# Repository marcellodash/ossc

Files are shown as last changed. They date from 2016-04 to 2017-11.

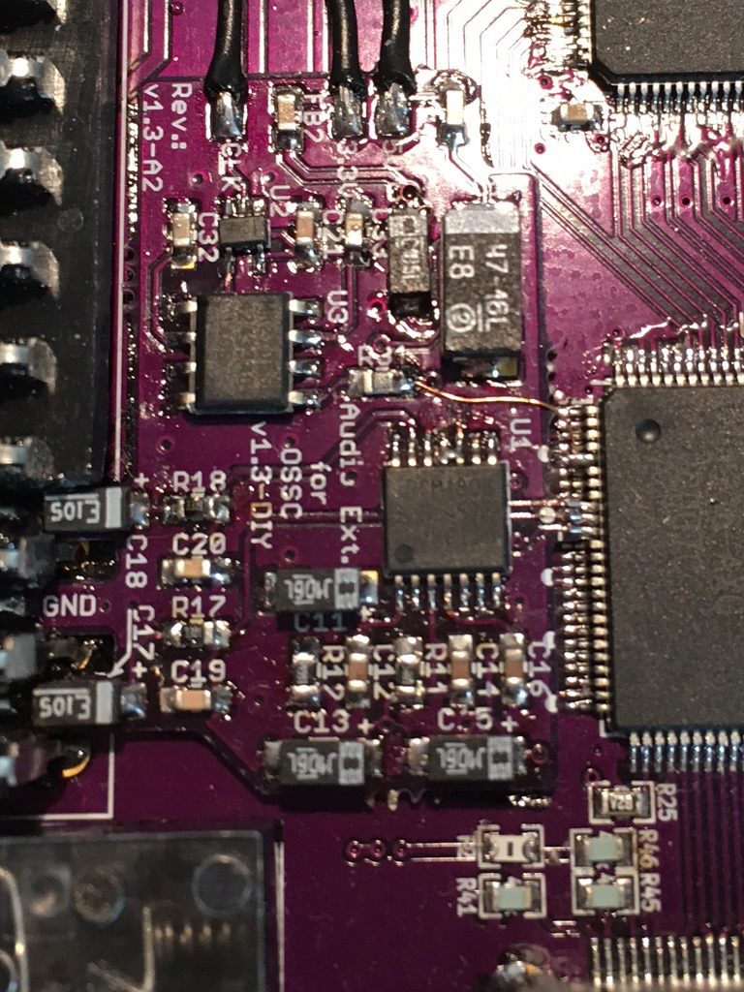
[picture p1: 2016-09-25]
diy-audio/installation/installation_mclk_10-v1.3.JPG

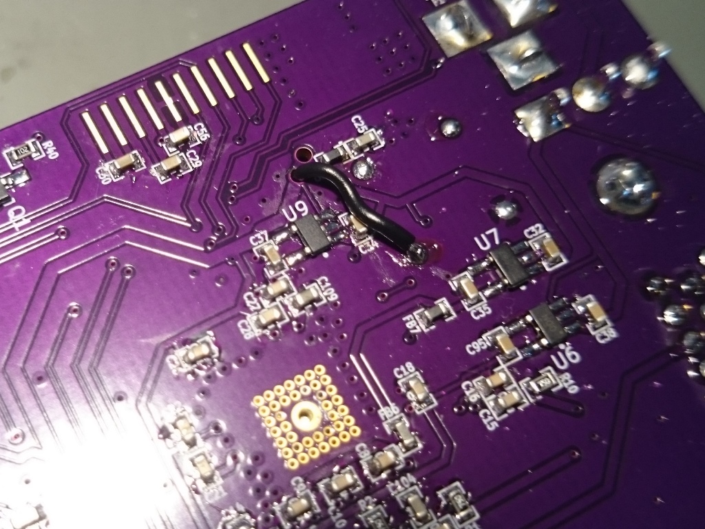
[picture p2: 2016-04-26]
diy-audio/installation/installation_ae_09.JPG

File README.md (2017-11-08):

Open Source Scan Converter
==============

Open Source Scan Converter is a low-latency video digitizer and scan conversion board designed mainly for connecting retro video game consoles and home computers into modern displays. Please check the [wikipage](http://junkerhq.net/xrgb/index.php?title=OSSC) for more detailed description and latest features.

Requirements for building and debugging firmware
---------------------------------------------------
* Hardware
  * OSSC board
  * USB Blaster compatible JTAG debugger, e.g. Terasic Blaster (for FW installation and debugging)
  * micro SD/SDHC card (for FW update via SD card)

* Software
  * [Altera Quartus II + Cyclone IV support](http://dl.altera.com/?edition=lite) (v 16.1 or higher - free Lite Edition suffices)
  * GCC (or another C compiler) for host architecture (for building a SD card image)
  * Make
  * [iconv](https://en.wikipedia.org/wiki/Iconv) (for building with JP lang menu)

Architecture
------------------------------
* [Reference board schematics](https://www.niksula.hut.fi/~mhiienka/ossc/diy-v1.5/ossc_v1.5-diy_schematic.pdf)
* [Reference PCB project](https://github.com/marqs85/ossc_pcb)

Building software image
--------------------------
1. Enter BSP directory:
~~~~
cd software/sys_controller_bsp
~~~~
2. (Optionally) edit BSP settings:
~~~~
nios2-bsp-editor
~~~~
3. Generate BSP:
~~~~
nios2-bsp-generate-files --bsp-dir . --settings settings.bsp
~~~~
NOTE: the previous step must be done every time after RTL/bitstream is built

4. Enter software root directory:
~~~~
cd software/sys_controller
~~~~
5. Build SW for target configuration:
~~~~
make [OPTIONS] [TARGET]
~~~~
OPTIONS may include following definitions:
* OSDLANG=JP (Japanese language menu)
* ENABLE_AUDIO=y (Includes audio setup code for v1.6 PCB / DIY audio add-on board)

TARGET is typically one of the following:
* all (Default target. Compiles an ELF for direct downloading to Nios2 during testing)
* generate_hex (Generates a memory initialization file required for bitstream)
* clean (cleans ELF and intermediate files. Should be invoked every time OPTIONS are changed between compilations, expect with generate_hex where it is done automatically)

6. Optionally test updated SW by downloading ELF to Nios2 CPU via JTAG (RTL-SW interface in active FW must be compatible new SW BSP configuration)
~~~~
nios2-download -g --accept-bad-sysid sys_controller.elf
~~~~

Building RTL / bitstream
--------------------------
1. Load the project (ossc.qpf) in Quartus
2. Generate the FPGA bitstream (Processing -> Start Compilation). NOTE: make sure software image (software/sys_controller/mem_init/sys_onchip_memory2_0.hex) is up to date before generating bitstream.
3. Ensure that there are no severe timing violations by looking into Timing Analyzer report

If only software image is updated, bitstream can be quickly rebuilt by running "Processing->Update Memory Initialization File" and "Processing->Start->Start Assembler" in Quartus.

Installing firmware via JTAG
--------------------------
The bitstream can be either directly programmed into FPGA (volatile method, suitable for quick testing), or into serial flash chip where it is automatically loaded every time FPGA is subsequently powered on (nonvolatile method, suitable for long-term use).

To program FPGA, open Programmer in Quartus, select your USB Blaster device, add configuration file (output_files/ossc.sof) and press Start

To program flash, FPGA configuration file must be first converted into JTAG indirect Configuration file (.jic). Open conversion tool ("File->Convert Programming Files") in Quartus, click "Open Conversion Setup Data", select "ossc.cof" and press Generate. Then open Programmer, add generated file (output_files/ossc.jic) and press Start after which flash is programmed. Installed/updated firmware is activated after power-cycling the board.

Generating SD card image
--------------------------
Bitstream file (Altera propiertary format) must be wrapped with custom header structure (including checksums) so that it can be processed reliably on the CPU. This can be done with included helper application which generates a disk image which can written to a SD card and subsequently loaded on OSSC:

1. Compile tools/create_fw_img.c
~~~~
cd tools && gcc create_fw_img.c -o create_fw_img
~~~~
2. Generate the firmware image:
~~~~
./create_fw_img <rbf> <version> [version_suffix]
~~~~
where
* \<rbf\> is RBF format bitstream file (typically ../output_files/ossc.rbf)
* \<version\> is version string (e.g. 0.78)
* \[version_suffix\] is optional max. 8 character suffix name (e.g. "mytest")

Debugging
--------------------------
1. Rebuild the software in debug mode:
~~~~
make clean && make APP_CFLAGS_DEBUG_LEVEL="-DDEBUG"
~~~~
NOTE: Fw update functionality via SD card is disabled in debug builds due to code space limitations. If audio support is enabled on debug build, other functionality needs to be disabled as well.

2. Program Nios2 CPU via JTAG and open terminal for UART
~~~~
nios2-download -g --accept-bad-sysid sys_controller.elf && nios2-terminal
~~~~
Remember to close nios2-terminal after debug session, otherwise any JTAG transactions will hang/fail.

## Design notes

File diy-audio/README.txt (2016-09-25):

The OSSC does not output audio over HDMI or DVI-D, respectively. This add on captures the analoge audio you feed over the SCART or audio 3.5mm stereo jack. The audio signal is digitalize and put into the IT6613E over the I2S audio interface.

Firmware
========
The IT6613E has to be programmed appropriately to insert audio to the digital video output. In the 'original' firmware audio is not taken into account. Therefore the firmware of the OSSC has to be updated.
You can grab the current firmware here: https://github.com/borti4938/ossc/tree/diy-audio/diy-audio/fw-build
I do my best to keep the firmware synchronized with updates by marqs85. However, as marqs includes more and more features to the firmware there might be a point where I have to cut features due to the lack of memory space.

PCB Production
==============
Choose the service you would ever like. I have uploaded the design to OSHPark, too.
VERY IMPORTANT: The substrate thickness has to be as thin as possible.
The PCB is design to sit between lifted pins of the IT6613 (the HDMI transmitter) and OSSC-PCB. Just look at the installation pictures to get an idea ;)
I have produced the PCBs with OSHPark and have chosen 0.8mm thickness. The PCB must not be thicker.
Link to PCB at OSHPark:
- https://oshpark.com/shared_projects/4u6ta1CE (for v1.3)
- https://oshpark.com/shared_projects/1sT4vN4I (for v1.5)
- https://oshpark.com/shared_projects/bOskL1g1 (for v1.5 with wired connection to the SCART)

Part list of the DIY-Audio PCB
==============================
running number ------ footprint(s) --------- device/part --------- package ----- mouser ordering key
     01         |  U1                 |  PCM1808               |  TSSOP14     |  595-PCM1808PWR
     02         |  U2                 |  74LVC1G34             |  SOT23-5     |  595-SN74LVC1G34DCKR
     03         |  U3                 |  MK2705SLF             |  SOIC8       |  972-MK2705SLF
     04         |  FB1, FB2           |  Ferrit Beat           |  SMD0603     |  81-BLM18PG471SN1D
     05         |  C1                 |  tantal-cap. 47uF/16V  |  SMD case C  |  74-293D476X9016C2TE3
     06         |  R11, R12           |  res. >2.2 kOhm        |  SMD0603     |  71-CRCW06034K99FKEAH (e.g. 4.99k)
     07         |  C11, C13, C15      |  tantal-cap. 10uF/6.3V |  SMD case A  |  74-TR3A106M6R3C1500
     08         |  C12, C14, C16, C21 | cap. 0.1uF/50V         |  SMD0603     |  77-VJ0603V104MXACBC
     09         |  C17, C18, C31      | tantal-cap. 1uF/16V    |  SMD case A  |  74-293D105X9016A2TE3
     10         |  R19, R20           | res. ***               |  SMD0603     |  see description below
     11         |  C19, C20           | cap. ***               |  SMD0603     |  see description below
     12         |  R31                | res. 33 Ohm            |  SMD0603     |  71-CRCW060333R0FKEAH
     13         |  C32, C33           | cap. 0.01uF/50V        |  SMD0603     |  77-VJ0603Y103KXACBC

RC-filtering of the Audio
=========================
The RC filters (R19,C19) and (R20,C20) mainly bandlimits the noise. The filter also avoids aliasing effects if the bandwith of the audio signal increases.
The PCM1808 samples the audio signal with 96kHz. This means that the cut-off frequency of the filters have to be 96kHz or below. The firmware will also allows you to further downsample the datastream to 48kHz. If you want to use that I recommend you to set the filter to 48kHz or below to avoid aliasing.
The cut-off frequency f_c of a simple RC low pass filter is determined by f_c = 1/(2*pi*R*C).
here is my choice which gives a cut-off frequency of 47.938kHz.
     10         |  R19, R20  |  res. 3.32 kOhm   |  SMD0603  |  71-CRCW0603-3.32K-E3  
     11         |  C19, C20  |  cap. 1000pF/50V  |  SMD0603  |  77-VJ0603Y102KXACBC

PCB-Installation
=================
(see pictures; assumes that at least the SCART connector has been desoldered)
01 - v1.3 - bend up pins 9, 10 and 11 of the IT6613 (v1.3 only!!!) (and eventually pin 5 - see External MCLK)
   - v1.5 - cut three wires between each pair of solder joints marked with I2S, WS and SCK (v1.5 only) (eventually lift pin 5 of the IT6613E - see External MCLK)
02 - make a placement check (might look different between v1.3 and v1.5)
03 - cut off the plastic around pin 2, 4 and 6 of the SCART connector if needed
04 - solder the IT6613 into place (if not done yet) and approximately fix the audio pcb into place (v1.5 does not sit under some pins)
05 - solder the SCART plug into place and solder the audio PCB onto the SCART connector (remind to check the pin assignment at the IT6613 during soldering the first leg)
06 - v1.3 - solder pin 9, 10 and 11 of the IT6613 onto the audio PCB (v1.3 only)
   - v1.5 - solder the three top solder joints on the OSSC PCB (I2S, WS and SCK) to the DIY audio PCB (v1.5 only)
07 - connect the wires
08 - 5V and 3.3V can be get from U5
09 - 27MHz from the crystal oscillator (pin between U7 and U9)
10 - Pin 5 of the IT6613E lifted and connected to R31 (top pad)

External MCLK
=============
The IT6613E derives the system clock for audio processing (audio master clock, MCLK) from the I2S input (I2S0, WS and SCK) by default. It is also possible to feed the MCLK into the IT6613E using pin 5 and setting appropriate register bits.
If you have problems with the internally derived MCLK of the IT6613E, you have to use the external MCLK. Problems mean that you might have audio dropouts or you simply hear nothing! Then you have to use the external MCLK.
Next to setting the option in the OSSC menu you might have to modify your OSSC a bit.
- older audio boards v1.5-A3x, v1.3-A3, and before: lift pin 5 of the IT6613E and connect the pin with R31 (top pad; see picture 10) 
- newer audio boards v1.3-A4: designed to lift pin 5 before installation. Nothing more to done.
- newer audio boards v1.5-A4x: lift pin 5 and connect the pin with the pad 'MCLK' on the audio add-on board

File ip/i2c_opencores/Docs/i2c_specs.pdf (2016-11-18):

I

2

# C-Master Core Specification

# Author: Richard Herveille

### rherveille@opencores.org

### Rev. 0.9 July 3, 2003

## This page has been intentionally left blank

### Revision History

Rev. | Date | Author | Description
0.1 | 17/02/01 | Richard Herveille | First draft release
0.2 | 01/03/01 | Richard Herveille | Some cleaning up throughout the document Added ‘Programming Examples’ section
0.3 | | Richard Herveille | Added some comments after core-changes - added BUSY bit (status register) - changed I2C IO for ASIC support - added comment for FGPA IO
0.4 | 10/19/01 | Richard Herveille | Changed core’s databus size to 8bit. Changed documentation to reflect changes. Changed port names to new naming convention.
0.5 | 18/02/02 | Richard Herveille | Changed table headers. Added OpenCores logo.
0.5a | 05/02/02 | Richard Herveille | Reviewed entire document.
0.6 | 21/03/02 | Richard Herveille | Added Appendix A, Synthesis Results
0.7 | 25/06/02 | Richard Herveille | Changed Prescale Register formula
0.8 | 30/12/02 | Richard Herveille | Added Multi-Master capabilities. New timing diagrams.
0.9 | 03/07/03 | Richard Herveille | Changed ‘0x5C’ to ‘0xAC’ in Example1. Changed ‘RW’ to ‘W’ in Command Register. Changed ‘RW’ to ‘W’ in Transmit Register.

OpenCores | I²
C-Master core | 7/3/2003
www.opencores.org | Rev 0.8 Preliminary | 1 of 15

1

# Introduction

I

2
C is a two-wire, bi-directional serial bus that provides a simple and efficient method of data exchange between devices. It is most suitable for applications requiring occasional communication over a short distance between many devices. The I²
C standard is a true
multi-master bus including collision detection and arbitration that prevents data corruption if two or more masters attempt to control the bus simultaneously.

The interface defines 3 transmission speeds:
- Normal: 100Kbps
- Fast: 400Kbps
- High speed: 3.5Mbps

Only 100Kbps and 400Kbps modes are supported directly. For High speed special IOs are needed. If these IOs are available and used, then High speed is also supported.

## FEATURES

- Compatible with Philips I²
C standard
- Multi Master Operation
- Software programmable clock frequency
- Clock Stretching and Wait state generation
- Software programmable acknowledge bit
- Interrupt or bit-polling driven byte-by-byte data-transfers
- Arbitration lost interrupt, with automatic transfer cancelation
- Start/Stop/Repeated Start/Acknowledge generation
- Start/Stop/Repeated Start detection
- Bus busy detection
- Supports 7 and 10bit addressing mode
- Operates from a wide range of input clock frequencies
- Static synchronous design
- Fully synthesizable

2

# IO ports

## 2.1 Core Parameters

Parameter | Type | Default | Description
ARST_LVL | Bit | 1’b0 | Asynchronous reset level

### 2.1.1 ARST_LVL

The asynchronous reset level can be set to either active high (1’b1) or active low (1’b0).

## 2.2 WISHBONE interface signals

Port | Width | Direction | Description
wb_clk_i | 1 | Input | Master clock
wb_rst_i | 1 | Input | Synchronous reset, active high
arst_i | 1 | Input | Asynchronous reset
wb_adr_i | 3 | Input | Lower address bits
wb_dat_i | 8 | Input | Data towards the core
wb_dat_o | 8 | Output | Data from the core
wb_we_i | 1 | Input | Write enable input
wb_stb_i | 1 | Input | Strobe signal/Core select input
wb_cyc_i | 1 | Input | Valid bus cycle input
wb_ack_o | 1 | Output | Bus cycle acknowledge output
wb_inta_o | 1 | Output | Interrupt signal output

The core features a WISHBONE RevB.3 compliant WISHBONE Classic interface. All output signals are registered. Each access takes 2 clock cycles.
arst_i is not a WISHBONE compatible signal. It is provided for FPGA implementations. Using [arst_i] instead of [wb_rst_i] can result in lower cell-usage and higher performance, because most FPGAs provide a dedicated asynchronous reset path. Use either [arst_i] or [wb_rst_i], tie the other to a negated state.

## 2.3 External connections

Port | Width | Direction | Description
scl_pad_i | 1 | Input | Serial Clock line input
scl_pad_o | 1 | Output | Serial Clock line output
scl_pad_oe | 1 | Output | Serial Clock line output enable
sda_pad_i | 1 | Input | Serial Data line input
sda_pad_o | 1 | Output | Serial Data line output
sda_pad_oe | 1 | Output | Serial Data line output enable

The I²
C interface uses a serial data line (SDA) and a serial clock line (SCL) for data transfers. All devices connected to these two signals must have open drain or open collector outputs. Both lines must be pulled-up to VCC by external resistors.

The tri-state buffers for the SCL and SDA lines must be added at a higher hierarchical level. Connections should be made according to the following figure:

For FPGA designs the compiler can automatically insert these buffers using the following VHDL code:

scl <= scl_pad_o when (scl_padoen_oe = ‘0’) else ‘Z’;
sda <= sda_pad_o when (sda_padoen_oe = ‘0’) else ‘Z’;
scl_pad_i <= scl;
scl_pad_i <= sda;

Verilog code:

assign scl = scl_padoen_oe ? 1’bz : scl_pad_o; assign sda = sda_padoen_oe ? 1’bz: sda_pad_o; assign scl_pad_i = scl;
assign sda_pad_i = sda;

scl_pad_i

scl_pad_o

scl_padoen_o
sda_pad_i

sda_pad_o

sda_padoen_o

SCL

SDA

3

# Registers

## 3.1 Registers list

Name | Address | Width | Access | Description
PRERlo | 0x00 | 8 | RW | Clock Prescale register lo-byte
PRERhi | 0x01 | 8 | RW | Clock Prescale register hi-byte
CTR | 0x02 | 8 | RW | Control register
TXR | 0x03 | 8 | W | Transmit register
RXR | 0x03 | 8 | R | Receive register
CR | 0x04 | 8 | W | Command register
SR | 0x04 | 8 | R | Status register

## 3.2 Register description

### 3.2.1 Prescale Register

This register is used to prescale the SCL clock line. Due to the structure of the I² C
interface, the core uses a 5*SCL clock internally. The prescale register must be programmed to this 5*SCL frequency (minus 1). Change the value of the prescale register only when the ‘EN’ bit is cleared.

Example: wb_clk_i = 32MHz, desired SCL = 100KHz
1 | 63 ( | ) | 3 ( | ) 5 100
32 | dec | F hex
KHz
MHz prescale | − = | = ∗ =

Reset value: 0xFFFF

### 3.2.2 Control register

Bit # | Access | Description
7 | RW | EN, I² C core enable bit. When set to ‘1’, the core is enabled. When set to ‘0’, the core is disabled.
6 | RW | IEN, I² C core interrupt enable bit. When set to ‘1’, interrupt is enabled. When set to ‘0’, interrupt is disabled.
5:0 | RW | Reserved
Reset Value: 0x00

The core responds to new commands only when the ‘EN’ bit is set. Pending commands are finished. Clear the ‘EN’ bit only when no transfer is in progress, i.e. after a STOP command, or when the command register has the STO bit set. When halted during a transfer, the core can hang the I²
C bus.

### 3.2.3 Transmit register

Bit # | Access | Description
7:1 | W | Next byte to transmit via I² C
0 | W | In case of a data transfer this bit represent the data’s LSB. In case of a slave address transfer this bit represents the RW bit. ‘1’ = reading from slave ‘0’ = writing to slave

Reset value: 0x00

### 3.2.4 Receive register

Bit # | Access | Description
7:0 | R | Last byte received via I² C
Reset value: 0x00

### 3.2.5 Command register

Bit # | Access | Description
7 | W | STA, generate (repeated) start condition
6 | W | STO, generate stop condition
5 | W | RD, read from slave
4 | W | WR, write to slave
3 | W | ACK, when a receiver, sent ACK (ACK = ‘0’) or NACK (ACK = ‘1’)
2:1 | W | Reserved
0 | W | IACK, Interrupt acknowledge. When set, clears a pending interrupt.
Reset Value: 0x00

The STA, STO, RD, WR, and IACK bits are cleared automatically. These bits are always read as zeros.

### 3.2.6 Status register

Bit # | Access | Description
7 | R | RxACK, Received acknowledge from slave. This flag represents acknowledge from the addressed slave. ‘1’ = No acknowledge received ‘0’ = Acknowledge received
6 | R | Busy, I² C bus busy ‘1’ after START signal detected ‘0’ after STOP signal detected
5 | R | AL, Arbitration lost This bit is set when the core lost arbitration. Arbitration is lost when: • a STOP signal is detected, but non requested • The master drives SDA high, but SDA is low. See bus-arbitration section for more information.
4:2 | R | Reserved
1 | R | TIP, Transfer in progress. ‘1’ when transferring data ‘0’ when transfer complete
0 | R | IF, Interrupt Flag. This bit is set when an interrupt is pending, which will cause a processor interrupt request if the IEN bit is set. The Interrupt Flag is set when: • one byte transfer has been completed • arbitration is lost

Reset Value: 0x00

Please note that all reserved bits are read as zeros. To ensure forward compatibility, they should be written as zeros.

4

# Operation

## 4.1 System Configuration

The I²
C system uses a serial data line (SDA) and a serial clock line (SCL) for data transfers. All devices connected to these two signals must have open drain or open collector outputs. The logic AND function is exercised on both lines with external pull-up resistors.

Data is transferred between a Master and a Slave synchronously to SCL on the SDA line on a byte-by-byte basis. Each data byte is 8 bits long. There is one SCL clock pulse for each data bit with the MSB being transmitted first. An acknowledge bit follows each transferred byte. Each bit is sampled during the high period of SCL; therefore, the SDA line may be changed only during the low period of SCL and must be held stable during the high period of SCL. A transition on the SDA line while SCL is high is interpreted as a command (see START and STOP signals).

## 4.2 I² C Protocol

Normally, a standard communication consists of four parts:
1) START signal generation
2) Slave address transfer
3) Data transfer
4) STOP signal generation
S | A7 | A6 | A5 | A4 | A3 | A2 | A1 | RW ACK | D7 | D6 | D5 | D4 | D3 | D2 | D1 | D0 NACK | P

SCL

SDA

1 | 2 | 3 | 4 | 5 | 6 | 7 | 8 | 9
MSB | LSB
1 | 2 | 3 | 4 | 5 | 6 | 7 | 8 | 9
MSB | LSB

### 4.2.1 START signal

When the bus is free/idle, meaning no master device is engaging the bus (both SCL and SDA lines are high), a master can initiate a transfer by sending a START signal. A START signal, usually referred to as the S-bit, is defined as a high-to-low transition of SDA while SCL is high. The START signal denotes the beginning of a new data transfer. A Repeated START is a START signal without first generating a STOP signal. The master uses this method to communicate with another slave or the same slave in a different transfer direction (e.g. from writing to a device to reading from a device) without releasing the bus.

The core generates a START signal when the STA-bit in the Command Register is set and the RD or WR bits are set. Depending on the current status of the SCL line, a START or Repeated START is generated.

### 4.2.2 Slave Address Transfer

The first byte of data transferred by the master immediately after the START signal is the slave address. This is a seven-bits calling address followed by a RW bit. The RW bit signals the slave the data transfer direction. No two slaves in the system can have the same address. Only the slave with an address that matches the one transmitted by the master will respond by returning an acknowledge bit by pulling the SDA low at the 9th SCL clock cycle.

Note: The core supports 10bit slave addresses by generating two address transfers. See the Philips I²
C specifications for more details.

The core treats a Slave Address Transfer as any other write action. Store the slave device’s address in the Transmit Register and set the WR bit. The core will then transfer the slave address on the bus.

### 4.2.3 Data Transfer

Once successful slave addressing has been achieved, the data transfer can proceed on a byte-by-byte basis in the direction specified by the RW bit sent by the master. Each transferred byte is followed by an acknowledge bit on the 9th SCL clock cycle. If the slave signals a No Acknowledge, the master can generate a STOP signal to abort the data transfer or generate a Repeated START signal and start a new transfer cycle.

If the master, as the receiving device, does not acknowledge the slave, the slave releases the SDA line for the master to generate a STOP or Repeated START signal.

To write data to a slave, store the data to be transmitted in the Transmit Register and set the WR bit. To read data from a slave, set the RD bit. During a transfer the core set the TIP flag, indicating that a Transfer is In Progress. When the transfer is done the TIP flag is reset, the IF flag set and, when enabled, an interrupt generated. The Receive Register contains valid data after the IF flag has been set. The user may issue a new write or read command when the TIP flag is reset.

### 4.2.4 STOP signal

The master can terminate the communication by generating a STOP signal. A STOP signal, usually referred to as the P-bit, is defined as a low-to-high transition of SDA while SCL is at logical ‘1’.

## 4.3 Arbitration Procedure

### 4.3.1 Clock Synchronization

The I²
C bus is a true multimaster bus that allows more than one master to be connected on it. If two or more masters simultaneously try to control the bus, a clock synchronization procedure determines the bus clock. Because of the wired-AND connection of the I²
C signals a high to low transition affects all devices connected to the bus. Therefore a high to low transition on the SCL line causes all concerned devices to count off their low period. Once a device clock has gone low it will hold the SCL line in that state until the clock high state is reached. Due to the wired-AND connection the SCL line will therefore be held low by the device with the longest low period, and held high by the device with the shortest high period.

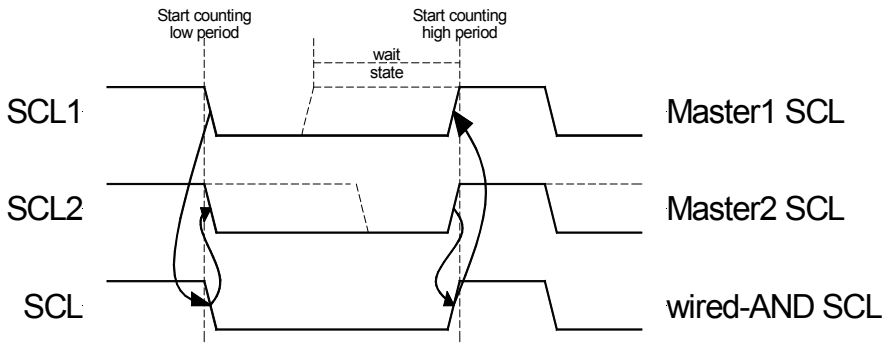
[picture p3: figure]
Start counting low period; wait state; Start counting high period; SCL1; SCL2; SCL; Master1 SCL; Master2 SCL; wired-AND SCL

### 4.3.2 Clock Stretching

Slave devices can use the clock synchronization mechanism to slow down the transfer bit rate. After the master has driven SCL low, the slave can drive SCL low for the required period and then release it. If the slave’s SCL low period is greater than the master’s SCL low period, the resulting SCL bus signal low period is stretched, thus inserting wait-states.

5

# Architecture

The I2C core is built around four primary blocks; the Clock Generator, the Byte Command Controller, the Bit Command Controller and the DataIO Shift Register. All other blocks are used for interfacing or for storing temporary values.

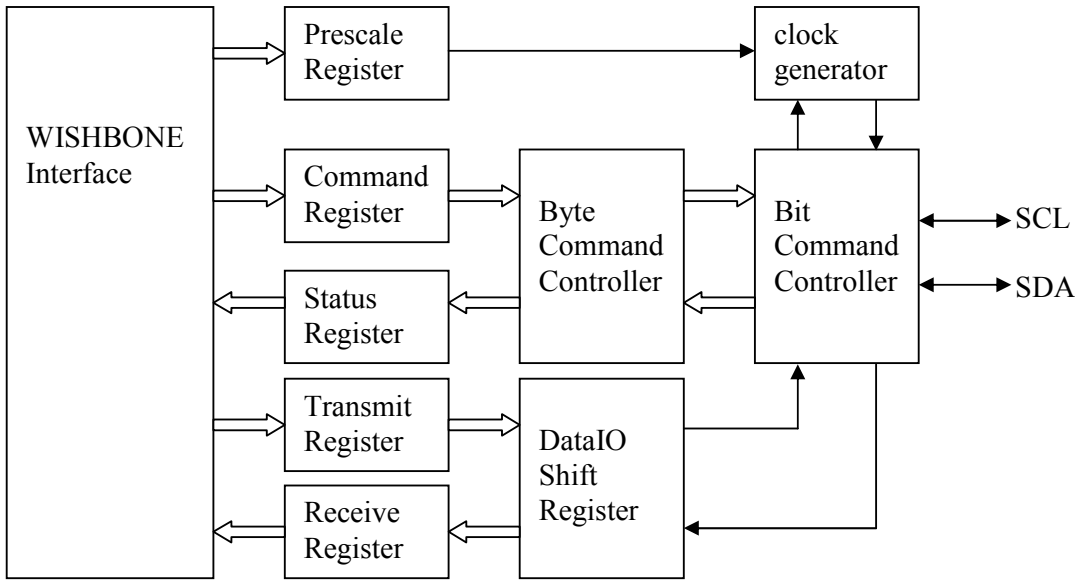
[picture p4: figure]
SCL; SDA; Prescale Register; clock generator; Command Register; Status Register; Byte Command Controller; Bit Command Controller; WISHBONE Interface; Transmit Register; Receive Register; DataIO Shift Register

## 5.1 Clock Generator

The Clock Generator generates an internal 4*Fscl clock enable signal that triggers all synchronous elements in the Bit Command Controller. It also handles clock stretching needed by some slaves.

## 5.2 Byte Command Controller

The Byte Command Controller handles I2C traffic at the byte level. It takes data from the Command Register and translates it into sequences based on the transmission of a single byte. By setting the START, STOP, and READ bit in the Command Register, for example, the Byte Command Controller generates a sequence that results in the

Fig. 5.1 Internal structure I2C Master Core

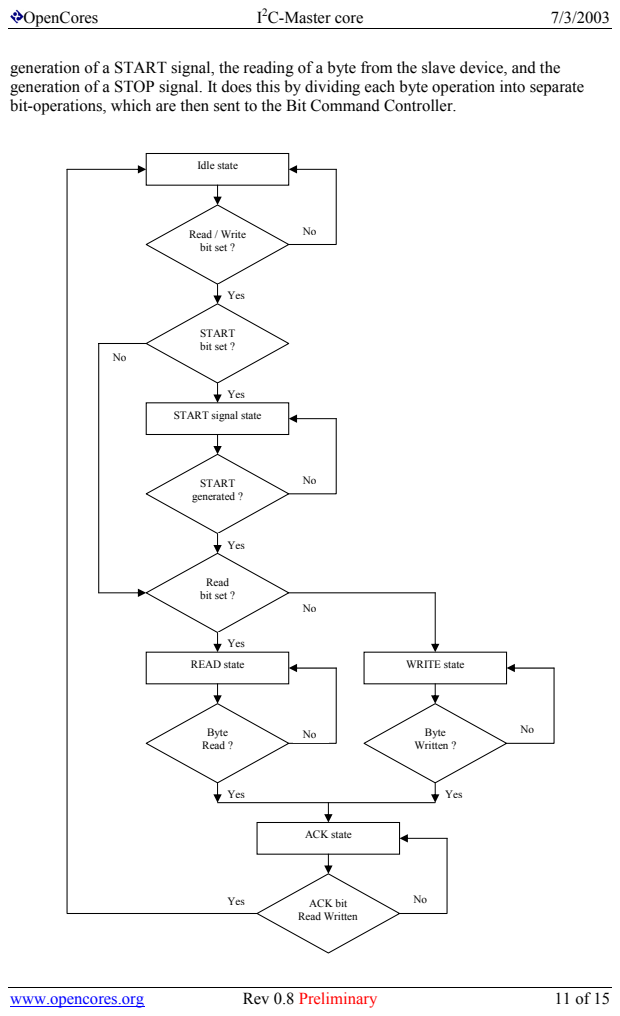
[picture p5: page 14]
Idle state; Read / Write bit set ?; Yes; START bit set ?; Read bit set ?; READ state; Byte Read ?; ACK state; WRITE state; Byte Written ?; ACK bit Read Written

generation of a START signal, the reading of a byte from the slave device, and the
generation of a STOP signal. It does this by dividing each byte operation into separate
bit-operations, which are then sent to the Bit Command Controller.

START signal state

START generated ?

## 5.3 Bit Command Controller

The Bit Command Controller handles the actual transmission of data and the generation of the specific levels for START, Repeated START, and STOP signals by controlling the SCL and SDA lines. The Byte Command Controller tells the Bit Command Controller which operation has to be performed. For a single byte read, the Bit Command Controller receives 8 separate read commands. Each bit-operation is divided into 5 pieces (idle and A, B, C, and D), except for a STOP operation which is divided into 4 pieces (idle and A, B, and C).

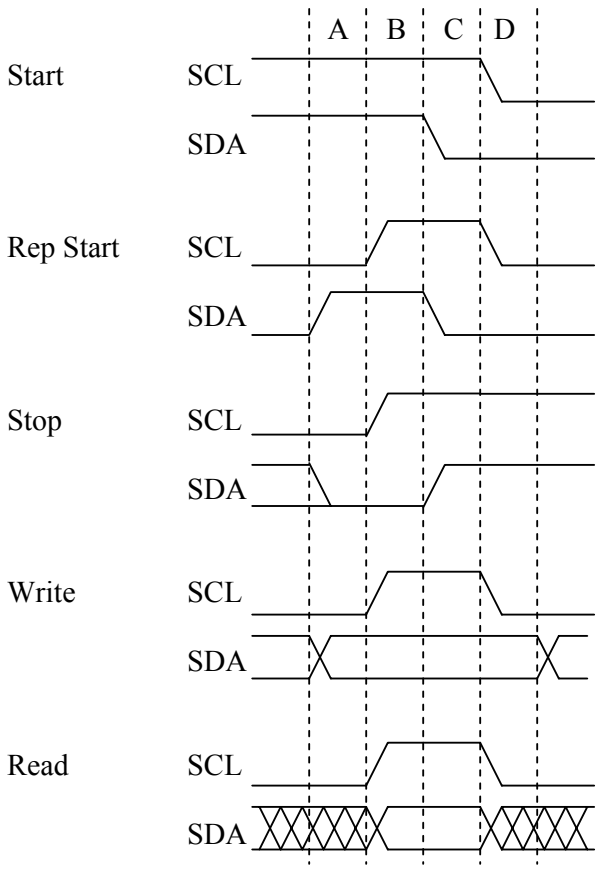
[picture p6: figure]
Start; SCL; SDA; Rep Start; Stop; Write; Read

## 5.4 DataIO Shift Register

The DataIO Shift Register contains the data associated with the current transfer. During a read action, data is shifted in from the SDA line. After a byte has been read the contents are copied into the Receive Register. During a write action, the Transmit Register’s contents are copied into the DataIO Shift Register and are then transmitted onto the SDA line.

6

# Programming examples

## Example 1

Write 1 byte of data to a slave.

Slave address = 0x51 (b”1010001”) Data to write = 0xAC

I2C Sequence:
1) generate start command
2) write slave address + write bit
3) receive acknowledge from slave
4) write data
5) receive acknowledge from slave
6) generate stop command

Commands:
1) write 0xA2 (address + write bit) to Transmit Register, set STA bit, set WR bit. -- wait for interrupt or TIP flag to negate --
2) read RxACK bit from Status Register, should be ‘0’.
write 0xAC to Transmit register, set STO bit, set WR bit.
-- wait for interrupt or TIP flag to negate --
3) read RxACK bit from Status Register, should be ‘0’.

Please note that the time for the Interrupt Service Routine is not shown here. It is assumed that the ISR is much faster then the I²
C cycle time, and therefore not visible.

## Example 2

Read a byte of data from an I2C memory device.

Slave address = 0x4E
Memory location to read from = 0x20

I2C sequence:
1) generate start signal
2) write slave address + write bit
3) receive acknowledge from slave
4) write memory location
5) receive acknowledge from slave
6) generate repeated start signal
7) write slave address + read bit
8) receive acknowledge from slave
9) read byte from slave
10) write no acknowledge (NACK) to slave, indicating end of transfer
11) generate stop signal

Commands:
1) write 0x9C (address + write bit) to Transmit Register, set STA bit, set WR bit. -- wait for interrupt or TIP flag to negate --
2) read RxACK bit from Status Register, should be ‘0’.
write 0x20 to Transmit register, set WR bit.
-- wait for interrupt or TIP flag to negate --
3) read RxACK bit from Status Register, should be ‘0’.
write 0x9D (address + read bit) to Transmit Register, set STA bit, set WR bit. -- wait for interrupt or TIP flag to negate --
4) set RD bit, set ACK to ‘1’ (NACK), set STO bit

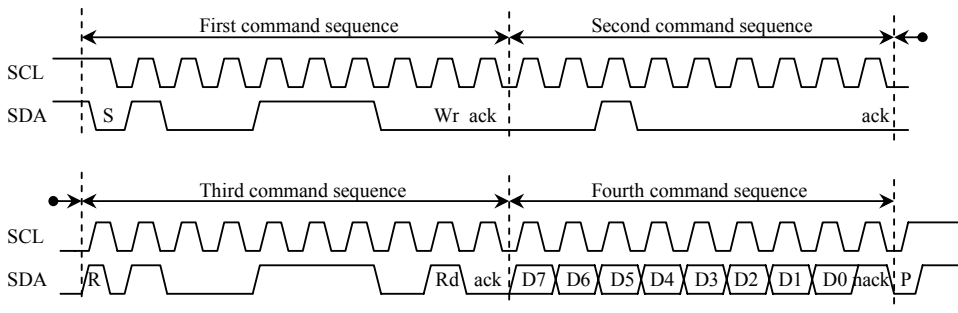
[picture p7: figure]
First command sequence; Second command sequence; SDA; Wr ack; ack; SCL; Third command sequence; Fourth command sequence

Please note that the time for the Interrupt Service Routine is not shown here. It is assumed that the ISR is much faster then the I²
C cycle time, and therefore not visible.
SDA | R | Rd ack | D7 D6 D5 D4 D3 D2 D1 D0 nack | P

# Appendix A

# Synthesis results

Synthesis tool: Synplify Pro

Technology | Device | Speed grade | Fmax | Resource usage
ACTEL | A54SX16ATQ100 | std | 58MHz | Modules: 352
Altera | EP10K50ETC144 | -3 | 82MHz | LCs: 294
| EP20K30ETC144 | -3 | 74MHz | ATOMS: 257
Xilinx | 2s15CS144 | -5 | 82MHz | LUTs: 229
| XCV50ECS144 | -8 | 118MHz | LUTs: 230

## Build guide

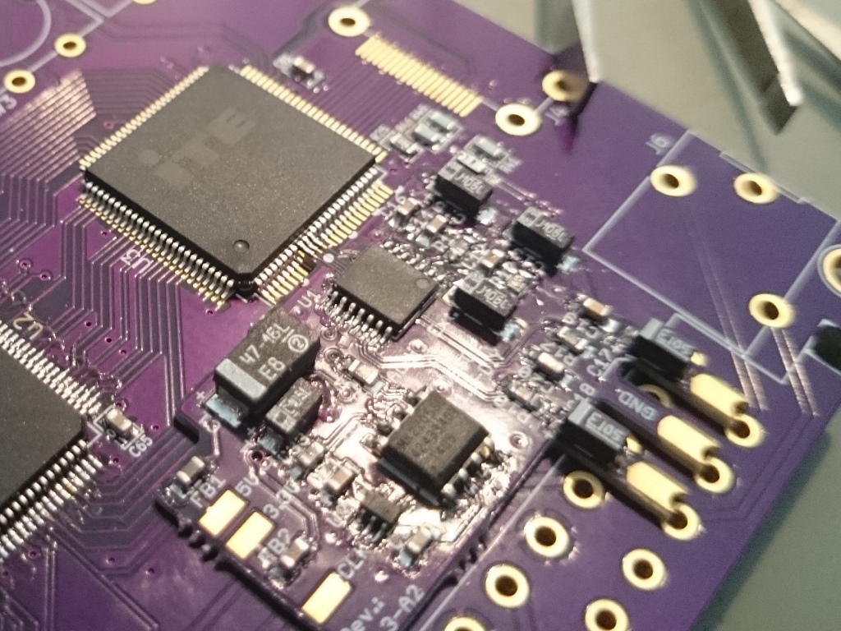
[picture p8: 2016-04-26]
diy-audio/installation/installation_ae_02.JPG

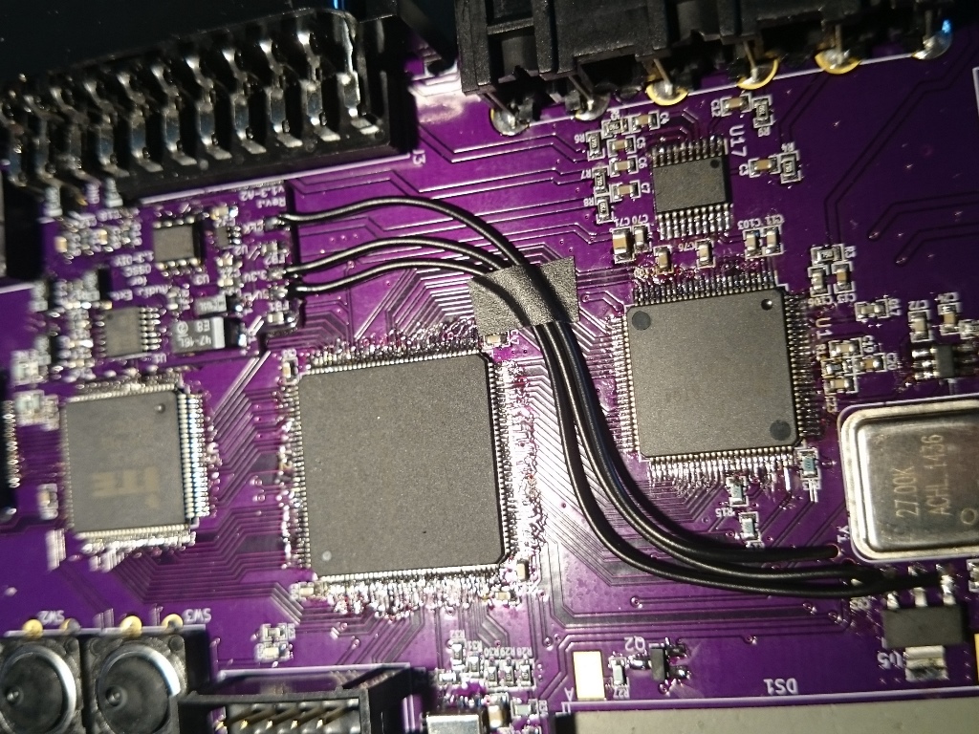
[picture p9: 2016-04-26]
diy-audio/installation/installation_ae_07.JPG

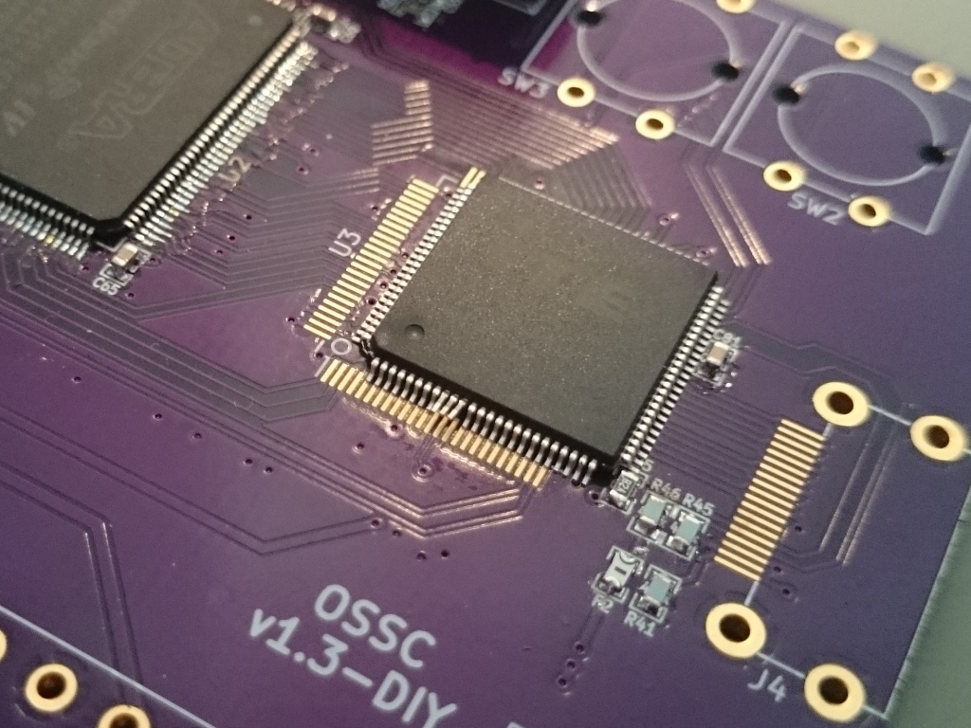
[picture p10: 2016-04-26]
diy-audio/installation/installation_ae_01-v1.3.JPG

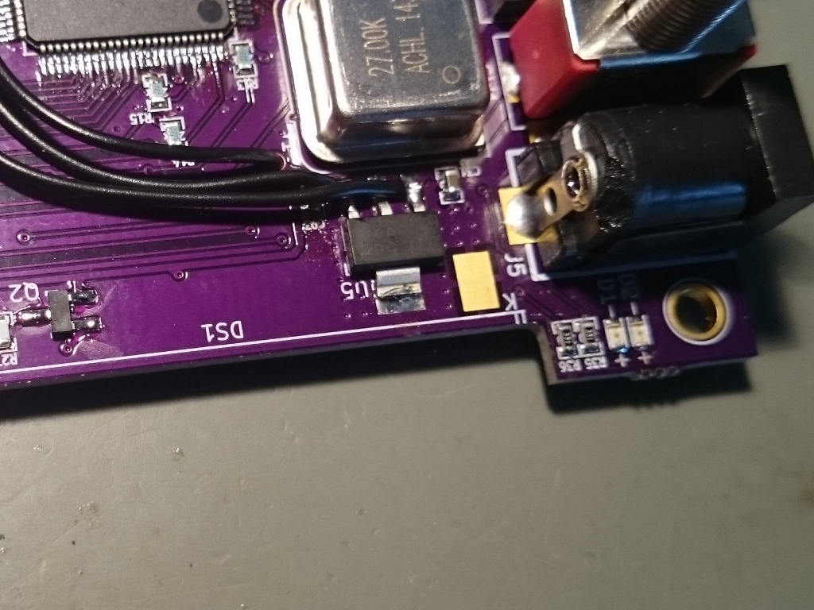
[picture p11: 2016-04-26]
diy-audio/installation/installation_ae_08.JPG

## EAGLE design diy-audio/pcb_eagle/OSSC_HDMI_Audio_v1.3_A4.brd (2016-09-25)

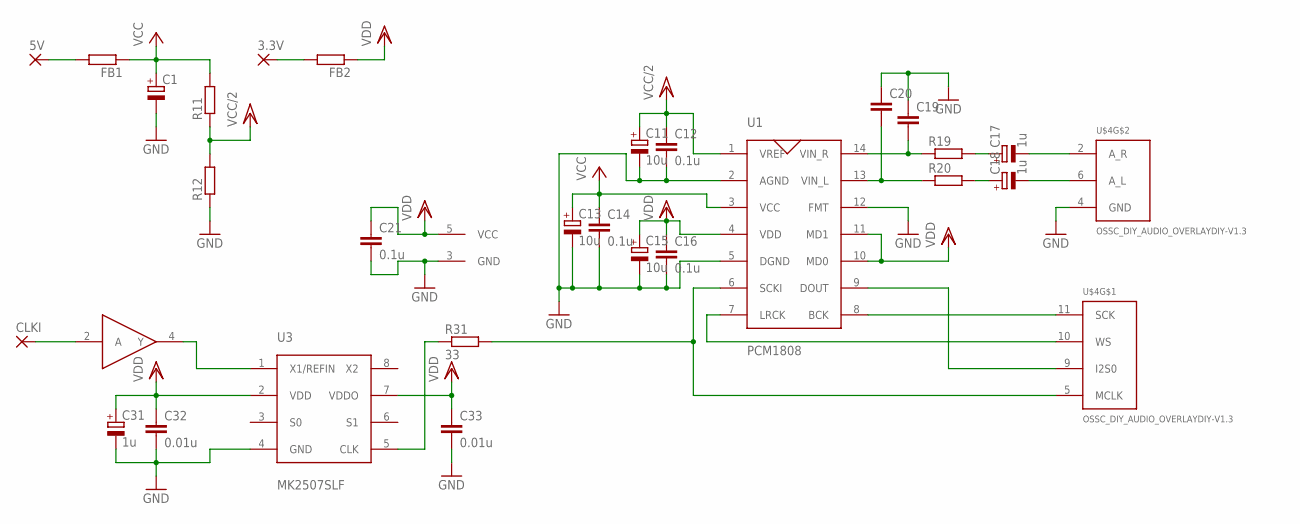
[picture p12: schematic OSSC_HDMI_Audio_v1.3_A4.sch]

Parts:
3.3V, 5V: SMD2; SMD1,27-2,54
C1: CPOL-EUSMCC; SMC_C
C11, C13, C15: 10u; SMC_A
C12, C14, C16, C21: 0.1u; C0603
C17, C18, C31: 1u; SMC_A
C19, C20: C-EUC0603; C0603
C32, C33: 0.01u; C0603
CLKI: SMD2; SMD1,27-2,54
FB1, FB2: R-EU_R0603; R0603
R11, R12, R19, R20: R-EU_R0603; R0603
R31: 33; R0603
U1: PCM1808
U2: 74LVC1G34; 74LVC1G34DCK
U3: MK2507SLF; SOIC8
U$4: OSSC_DIY_AUDIO_OVERLAYDIY-V1.3; OSSC_OVERLAY_V1.3

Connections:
GND: C1.-, C11.-, C12.2, C13.-, C14.2, C15.-, C16.2, C19.1, C20.1, C21.2, C31.-, C32.2, C33.2, R12.1, U1.2 (AGND), U1.5 (DGND), U1.12 (FMT), U2.3 (GND), U3.4 (GND), U$4.4 (GND)
unnamed: C18.-, U$4.6 (A_L)
unnamed: C17.-, U$4.2 (A_R)
unnamed: C17.+, R19.2
unnamed: C19.2, R19.1, U1.14 (VIN_R)
unnamed: C20.2, R20.1, U1.13 (VIN_L)
unnamed: C18.+, R20.2
unnamed: R31.1, U3.5 (CLK)
unnamed: U2.4 (Y), U3.1 (X1/REFIN)
unnamed: CLKI.1, U2.2 (A)
unnamed: 5V.1, FB1.2
unnamed: 3.3V.1, FB2.2
unnamed: U1.7 (LRCK), U$4.10 (WS)
unnamed: U1.8 (BCK), U$4.11 (SCK)
unnamed: U1.9 (DOUT), U$4.9 (I2S0)
unnamed: R31.2, U1.6 (SCKI), U$4.5 (MCLK)
VCC: C1.+, C13.+, C14.1, FB1.1, R11.2, U1.3 (VCC)
VCC/2: C11.+, C12.1, R11.1, R12.2, U1.1 (VREF)
VDD: C15.+, C16.1, C21.1, C31.+, C32.1, C33.1, FB2.1, U1.4 (VDD), U1.10 (MD0), U1.11 (MD1), U2.5 (VCC), U3.2 (VDD), U3.7 (VDDO)

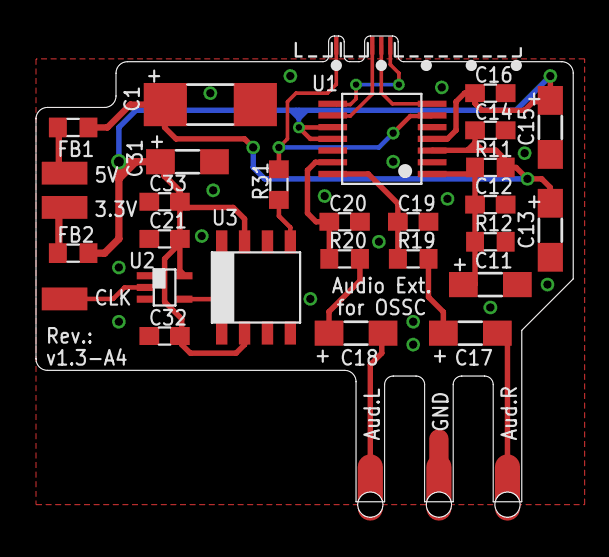
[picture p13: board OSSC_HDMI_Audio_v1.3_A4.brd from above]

Board: 2 copper layers, 29.8 x 25.9 mm, 29 parts (0 on the bottom side), 19 nets.

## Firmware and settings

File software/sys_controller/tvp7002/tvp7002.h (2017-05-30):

//
// Copyright (C) 2015-2016  Markus Hiienkari <mhiienka@niksula.hut.fi>
//
// This file is part of Open Source Scan Converter project.
//
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

#ifndef TVP7002_H_
#define TVP7002_H_

#include "tvp7002_regs.h"
#include "video_modes.h"
#include "sysconfig.h"

#define DEFAULT_VSYNC_THOLD 0x44
#define DEFAULT_LINELEN_TOL 0x06

#define TVP_INTCLK_HZ       6500000UL
#define TVP_EXTCLK_HZ       27000000UL

typedef enum {
    TVP_INPUT1 = 0,
    TVP_INPUT2 = 1,
    TVP_INPUT3 = 2
} tvp_input_t;

typedef enum {
    REFCLK_EXT27    = 0,
    REFCLK_INTCLK   = 1
} tvp_refclk_t;

typedef struct {
    const char *name;
    alt_u16 R_Y;
    alt_u16 R_Pb;
    alt_u16 R_Pr;
    alt_u16 G_Y;
    alt_u16 G_Pb;
    alt_u16 G_Pr;
    alt_u16 B_Y;
    alt_u16 B_Pb;
    alt_u16 B_Pr;
} ypbpr_to_rgb_csc_t;

typedef struct {
    alt_u8 r_f_off;
    alt_u8 g_f_off;
    alt_u8 b_f_off;
    alt_u8 r_f_gain;
    alt_u8 g_f_gain;
    alt_u8 b_f_gain;
} __attribute__((packed)) color_setup_t;


inline alt_u32 tvp_readreg(alt_u32 regaddr);

inline void tvp_writereg(alt_u32 regaddr, alt_u8 data);

inline void tvp_reset();

inline void tvp_disable_output();

inline void tvp_enable_output();

inline void tvp_set_hpllcoast(alt_u8 pre, alt_u8 post);

inline void tvp_set_linelen_tol(alt_u8 val);

inline void tvp_set_ssthold(alt_u8 vsdetect_thold);

void tvp_init();

void tvp_set_fine_gain_offset(color_setup_t *col);

void tvp_setup_hpll(alt_u16 h_samplerate, alt_u16 refclks_per_line, alt_u8 plldivby2);

void tvp_sel_clk(tvp_refclk_t refclk);

void tvp_sel_csc(const ypbpr_to_rgb_csc_t *csc);

void tvp_set_lpf(alt_u8 val);

void tvp_set_sync_lpf(alt_u8 val);

alt_u8 tvp_set_hpll_phase(alt_u8 val, alt_u8 sample_mult);

void tvp_set_sog_thold(alt_u8 val);

void tvp_set_alc(alt_u8 en_alc, video_type type, alt_u8 h_syncinlen);

void tvp_source_setup(video_type type, alt_u16 h_samplerate, alt_u16 refclks_per_line, alt_u8 plldivby2, alt_u8 h_syncinlen, alt_u8 pre_coast, alt_u8 post_coast, alt_u8 vsync_thold);

void tvp_source_sel(tvp_input_t input, video_format fmt);

alt_u8 tvp_check_sync(tvp_input_t input, video_format fmt);

#endif /* TVP7002_H_ */

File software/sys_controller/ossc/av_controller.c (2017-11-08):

//
// Copyright (C) 2015-2017  Markus Hiienkari <mhiienka@niksula.hut.fi>
//
// This file is part of Open Source Scan Converter project.
//
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

#include <stdio.h>
#include <unistd.h>
#include "system.h"
#include "string.h"
#include "altera_avalon_pio_regs.h"
#include "i2c_opencores.h"
#include "av_controller.h"
#include "tvp7002.h"
#include "ths7353.h"
#include "pcm1862.h"
#include "video_modes.h"
#include "lcd.h"
#include "flash.h"
#include "sdcard.h"
#include "menu.h"
#include "avconfig.h"
#include "sysconfig.h"
#include "firmware.h"
#include "userdata.h"
#include "it6613.h"
#include "it6613_sys.h"
#include "HDMI_TX.h"
#include "hdmitx.h"
#include "sd_io.h"

#define STABLE_THOLD            1
#define MIN_LINES_PROGRESSIVE   200
#define MIN_LINES_INTERLACED    400
#define SYNC_LOCK_THOLD         3
#define SYNC_LOSS_THOLD         -5
#define STATUS_TIMEOUT          10000

alt_u16 sys_ctrl;

// Current mode
avmode_t cm;

extern mode_data_t video_modes[];
extern ypbpr_to_rgb_csc_t csc_coeffs[];
extern alt_u16 rc_keymap[REMOTE_MAX_KEYS];
extern alt_u16 rc_keymap_default[REMOTE_MAX_KEYS];
extern alt_u32 remote_code;
extern alt_u32 btn_code, btn_code_prev;
extern alt_u8 remote_rpt, remote_rpt_prev;
extern avconfig_t tc;

alt_u8 target_typemask;
alt_u8 target_type;
alt_u8 stable_frames;
alt_u8 update_cur_vm;

alt_u8 vm_sel, vm_edit, profile_sel, lt_sel;
alt_u16 tc_h_samplerate, tc_h_synclen, tc_h_bporch, tc_h_active, tc_v_synclen, tc_v_bporch, tc_v_active;

char row1[LCD_ROW_LEN+1], row2[LCD_ROW_LEN+1], menu_row1[LCD_ROW_LEN+1], menu_row2[LCD_ROW_LEN+1];

extern alt_u8 menu_active;
avinput_t target_mode;

alt_u8 pcm1862_active;


inline void lcd_write_menu()
{
    lcd_write((char*)&menu_row1, (char*)&menu_row2);
}

inline void lcd_write_status() {
    lcd_write((char*)&row1, (char*)&row2);
}

#ifdef ENABLE_AUDIO
inline void SetupAudio(tx_mode_t mode)
{
    // shut down audio-tx before setting new config (recommended for changing audio-tx config)
    DisableAudioOutput();
    EnableAudioInfoFrame(FALSE, NULL);

    if (mode == TX_HDMI) {
        alt_u32 pclk_out = (TVP_EXTCLK_HZ/cm.clkcnt)*video_modes[cm.id].h_total*cm.sample_mult*(cm.fpga_vmultmode+1);

        pclk_out *= 1+cm.tx_pixelrep;

        printf("PCLK_out: %luHz\n", pclk_out);
#ifdef EXT_MCLK
        EnableAudioOutput4OSSC(pclk_out, tc.audio_ext_mclk, tc.audio_dw_sampl, tc.audio_swap_lr);
#else
        EnableAudioOutput4OSSC(pclk_out, tc.audio_dw_sampl, tc.audio_swap_lr);
#endif
        HDMITX_SetAudioInfoFrame((BYTE)tc.audio_dw_sampl);
#ifdef DEBUG
        Switch_HDMITX_Bank(1);
        usleep(1000);
        alt_u32 cts = 0;
        cts |= read_it2(0x35) >> 4;
        cts |= read_it2(0x36) << 4;
        cts |= read_it2(0x37) << 12;
        printf("CTS: %lu\n", cts);
#endif
    }
}
#endif

inline void TX_enable(tx_mode_t mode)
{
    // shut down TX before setting new config
    SetAVMute(TRUE);
    DisableVideoOutput();
    EnableAVIInfoFrame(FALSE, NULL);

    //Setup TX configuration
    //TODO: set pclk target and VIC dynamically
    EnableVideoOutput(PCLK_MEDIUM, COLOR_RGB444, COLOR_RGB444, !mode);

    if (mode == TX_HDMI) {
        HDMITX_SetAVIInfoFrame(HDMI_Unkown, 0, 0, tc.hdmi_itc, cm.hdmitx_pixr_ifr);
        cm.cc.hdmi_itc = tc.hdmi_itc;
    }

#ifdef ENABLE_AUDIO
    SetupAudio(mode);
#endif

    // start TX
    SetAVMute(FALSE);
}

void set_lpf(alt_u8 lpf)
{
    alt_u32 pclk;
    pclk = (TVP_EXTCLK_HZ/cm.clkcnt)*video_modes[cm.id].h_total;
    printf("PCLK_in: %luHz\n", pclk);

    //Auto
    if (lpf == 0) {
        switch (target_type) {
        case VIDEO_PC:
            tvp_set_lpf((pclk < 30000000) ? 0x0F : 0);
            ths_set_lpf(THS_LPF_BYPASS);
            break;
        case VIDEO_HDTV:
            tvp_set_lpf(0);
            ths_set_lpf(THS_LPF_BYPASS);
            break;
        case VIDEO_EDTV:
            tvp_set_lpf(0);
            ths_set_lpf(1);
            break;
        case VIDEO_SDTV:
        case VIDEO_LDTV:
        default:
            tvp_set_lpf(0);
            ths_set_lpf(0);
            break;
        }
    } else {
        tvp_set_lpf((tc.video_lpf == 2) ? 0x0F : 0);
        ths_set_lpf((tc.video_lpf > 2) ? (VIDEO_LPF_MAX-tc.video_lpf) : THS_LPF_BYPASS);
    }
}

inline int check_linecnt(alt_u8 progressive, alt_u32 totlines) {
    if (progressive)
        return (totlines >= MIN_LINES_PROGRESSIVE);
    else
        return (totlines >= MIN_LINES_INTERLACED);
}

// Check if input video status / target configuration has changed
status_t get_status(tvp_input_t input, video_format format)
{
    alt_u32 data1, data2;
    alt_u32 totlines, clkcnt;
    alt_u8 progressive;
    //alt_u8 refclk;
    alt_u8 sync_active;
    alt_u8 vsyncmode;
    alt_u16 totlines_tvp;
    alt_u16 h_samplerate;
    status_t status;
    static alt_8 act_ctr;
    alt_u32 ctr;
    int valid_linecnt;
    alt_u8 h_mult;

    status = NO_CHANGE;

    // Wait until vsync active (avoid noise coupled to I2C bus on earlier prototypes)
    for (ctr=0; ctr<STATUS_TIMEOUT; ctr++) {
        if (!(IORD_ALTERA_AVALON_PIO_DATA(PIO_2_BASE) & (1<<31))) {
            //printf("ctrval %u\n", ctr);
            break;
        }
    }

    sync_active = tvp_check_sync(input, format);
    vsyncmode = cm.sync_active ? ((IORD_ALTERA_AVALON_PIO_DATA(PIO_2_BASE) >> 16) & 0x3) : 0;

    // Read sync information from TVP7002 status registers
    data1 = tvp_readreg(TVP_LINECNT1);
    data2 = tvp_readreg(TVP_LINECNT2);
    totlines = ((data2 & 0x0f) << 8) | data1;
    progressive = !!(data2 & (1<<5));
    cm.macrovis = !!(data2 & (1<<6));
    data1 = tvp_readreg(TVP_CLKCNT1);
    data2 = tvp_readreg(TVP_CLKCNT2);
    clkcnt = ((data2 & 0x0f) << 8) | data1;

    // Read how many lines TVP7002 outputs in reality (valid only if output enabled)
    totlines_tvp = ((IORD_ALTERA_AVALON_PIO_DATA(PIO_2_BASE) >> 18) & 0x7ff)+1;

    // NOTE: "progressive" may not have correct value if H-PLL is not locked (!cm.sync_active)
    if ((vsyncmode == 0x2) || (!cm.sync_active && (totlines < MIN_LINES_INTERLACED))) {
        progressive = 1;
    } else if (vsyncmode == 0x1) {
        progressive = 0;
        totlines = totlines_tvp; //compensate skipped vsync
    }

    valid_linecnt = check_linecnt(progressive, totlines);

    // TVP7002 may randomly report "no sync" (especially with arcade boards),
    // thus disable output only after N consecutive "no sync"-events
    if (!cm.sync_active && sync_active && valid_linecnt) {
        printf("Sync up in %d...\n", SYNC_LOCK_THOLD-act_ctr);
        if (act_ctr >= SYNC_LOCK_THOLD) {
            act_ctr = 0;
            cm.sync_active = 1;
            status = ACTIVITY_CHANGE;
        } else {
            act_ctr++;
        }
    } else if (cm.sync_active && (!sync_active || !valid_linecnt)) {
        printf("Sync down in %d...\n", act_ctr-SYNC_LOSS_THOLD);
        if (act_ctr <= SYNC_LOSS_THOLD) {
            act_ctr = 0;
            cm.sync_active = 0;
            status = ACTIVITY_CHANGE;
        } else {
            act_ctr--;
        }
    } else {
        act_ctr = 0;
    }

    if (valid_linecnt) {
        // Line count reported in TVP7002 status registers is sometimes +-1 line off and may alternate with correct value. Ignore these events
        if ((totlines > cm.totlines+1) || (totlines+1 < cm.totlines) || (clkcnt != cm.clkcnt) || (progressive != cm.progressive)) {
            printf("totlines: %lu (cur) / %lu (prev), clkcnt: %lu (cur) / %lu (prev). totlines_tvp: %u, VSM: %u\n", totlines, cm.totlines, clkcnt, cm.clkcnt, totlines_tvp, vsyncmode);
            /*if (!cm.sync_active)
                act_ctr = 0;*/
            stable_frames = 0;
        } else if (stable_frames != STABLE_THOLD) {
            stable_frames++;
            if (stable_frames == STABLE_THOLD)
                status = (status < MODE_CHANGE) ? MODE_CHANGE : status;
        }

        if ((tc.pm_240p != cm.cc.pm_240p) ||
            (tc.pm_384p != cm.cc.pm_384p) ||
            (tc.pm_480i != cm.cc.pm_480i) ||
            (tc.pm_480p != cm.cc.pm_480p) ||
            (tc.pm_1080i != cm.cc.pm_1080i) ||
            (tc.l2_mode != cm.cc.l2_mode) ||
            (tc.l3_mode != cm.cc.l3_mode) ||
            (tc.l4_mode != cm.cc.l4_mode) ||
            (tc.l5_mode != cm.cc.l5_mode) ||
            (tc.l5_fmt != cm.cc.l5_fmt) ||
            (tc.tvp_hpll2x != cm.cc.tvp_hpll2x) ||
            (tc.upsample2x != cm.cc.upsample2x) ||
            (tc.vga_ilace_fix != cm.cc.vga_ilace_fix))
            status = (status < MODE_CHANGE) ? MODE_CHANGE : status;

        if ((tc.s480p_mode != cm.cc.s480p_mode) && (video_modes[cm.id].v_total == 525))
            status = (status < MODE_CHANGE) ? MODE_CHANGE : status;

        if (update_cur_vm) {
            tvp_setup_hpll(cm.sample_mult*video_modes[cm.id].h_total, clkcnt, cm.cc.tvp_hpll2x && (video_modes[cm.id].flags & MODE_PLLDIVBY2));
            status = (status < INFO_CHANGE) ? INFO_CHANGE : status;
        }

        cm.totlines = totlines;
        cm.clkcnt = clkcnt;
        cm.progressive = progressive;
    }

    if ((tc.sl_mode != cm.cc.sl_mode) ||
        (tc.sl_type != cm.cc.sl_type) ||
        (tc.sl_str != cm.cc.sl_str) ||
        (tc.sl_id != cm.cc.sl_id) ||
        (tc.h_mask != cm.cc.h_mask) ||
        (tc.v_mask != cm.cc.v_mask) ||
        (tc.mask_br != cm.cc.mask_br) ||
        (tc.ar_256col != cm.cc.ar_256col) ||
        (tc.reverse_lpf != cm.cc.reverse_lpf))
        status = (status < INFO_CHANGE) ? INFO_CHANGE : status;

    if (tc.sampler_phase != cm.cc.sampler_phase) {
        cm.sample_sel = tvp_set_hpll_phase(tc.sampler_phase, cm.sample_mult);
        status = (status < INFO_CHANGE) ? INFO_CHANGE : status;
    }

    if (tc.sync_vth != cm.cc.sync_vth)
        tvp_set_sog_thold(tc.sync_vth);

    if (tc.linelen_tol != cm.cc.linelen_tol)
        tvp_set_linelen_tol(tc.linelen_tol);

    if (tc.vsync_thold != cm.cc.vsync_thold)
        tvp_set_ssthold(tc.vsync_thold);

    if ((tc.pre_coast != cm.cc.pre_coast) || (tc.post_coast != cm.cc.post_coast))
        tvp_set_hpllcoast(tc.pre_coast, tc.post_coast);

    if (tc.ypbpr_cs != cm.cc.ypbpr_cs)
        tvp_sel_csc(&csc_coeffs[tc.ypbpr_cs]);

    if (tc.video_lpf != cm.cc.video_lpf)
        set_lpf(tc.video_lpf);

    if (tc.sync_lpf != cm.cc.sync_lpf)
        tvp_set_sync_lpf(tc.sync_lpf);

    if (!memcmp(&tc.col, &cm.cc.col, sizeof(color_setup_t)))
        tvp_set_fine_gain_offset(&cm.cc.col);

#ifdef ENABLE_AUDIO
    if ((tc.audio_dw_sampl != cm.cc.audio_dw_sampl) ||
#ifdef MANUAL_CTS
        (tc.edtv_l2x != cm.cc.edtv_l2x) ||
        (tc.interlace_pt != cm.cc.interlace_pt) ||
        update_cur_vm ||
#endif
#ifdef EXT_MCLK
        (tc.audio_ext_mclk != cm.cc.audio_ext_mclk) ||
#endif
        (tc.audio_swap_lr != cm.cc.audio_swap_lr))
        SetupAudio(tc.tx_mode);
#endif

    cm.cc = tc;
    update_cur_vm = 0;

    return status;
}
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
int main()
{
    tvp_input_t target_input = 0;
    ths_input_t target_ths = 0;
    pcm_input_t target_pcm = 0;
    video_format target_format = 0;

    alt_u8 av_init = 0;
    status_t status;

    alt_u32 input_vec;

    int init_stat;

    init_stat = init_hw();

    if (init_stat >= 0) {
        printf("### DIY VIDEO DIGITIZER / SCANCONVERTER INIT OK ###\n\n");
        sniprintf(row1, LCD_ROW_LEN+1, "OSSC  fw. %u.%.2u" FW_SUFFIX1 FW_SUFFIX2, FW_VER_MAJOR, FW_VER_MINOR);
#ifndef DEBUG
        strncpy(row2, "2014-2017  marqs", LCD_ROW_LEN+1);
#else
        strncpy(row2, "** DEBUG BUILD *", LCD_ROW_LEN+1);
#endif
        lcd_write_status();
        usleep(500000);
    } else {
        sniprintf(row1, LCD_ROW_LEN+1, "Init error  %d", init_stat);
        strncpy(row2, "", LCD_ROW_LEN+1);
        lcd_write_status();
        while (1) {}
    }

    if (tc.def_input < AV_LAST)
        target_mode = tc.def_input;

    // Mainloop
    while(1) {
        // Read remote control and PCB button status
        input_vec = IORD_ALTERA_AVALON_PIO_DATA(PIO_1_BASE);
        remote_code = input_vec & RC_MASK;
        btn_code = ~input_vec & PB_MASK;
        remote_rpt = input_vec >> 24;

        if ((remote_rpt == 0) || ((remote_rpt > 1) && (remote_rpt < 6)) || (remote_rpt == remote_rpt_prev))
            remote_code = 0;

        parse_control();

        if (menu_active)
            display_menu(0);

        if (target_mode == cm.avinput)
            target_mode = AV_KEEP;

        switch (target_mode) {
        case AV1_RGBs:
            target_input = TVP_INPUT1;
            target_format = FORMAT_RGBS;
            target_typemask = VIDEO_LDTV|VIDEO_SDTV|VIDEO_EDTV|VIDEO_HDTV;
            target_ths = THS_INPUT_B;
            target_pcm = PCM_INPUT4;
            break;
        case AV1_RGsB:
            target_input = TVP_INPUT1;
            target_format = FORMAT_RGsB;
            target_typemask = VIDEO_LDTV|VIDEO_SDTV|VIDEO_EDTV|VIDEO_HDTV;
            target_ths = THS_INPUT_B;
            target_pcm = PCM_INPUT4;
            break;
        case AV1_YPBPR:
            target_input = TVP_INPUT1;
            target_format = FORMAT_YPbPr;
            target_typemask = VIDEO_LDTV|VIDEO_SDTV|VIDEO_EDTV|VIDEO_HDTV;
            target_ths = THS_INPUT_B;
            target_pcm = PCM_INPUT4;
            break;
        case AV2_YPBPR:
            target_input = TVP_INPUT1;
            target_format = FORMAT_YPbPr;
            target_typemask = VIDEO_LDTV|VIDEO_SDTV|VIDEO_EDTV|VIDEO_HDTV;
            target_ths = THS_INPUT_A;
            target_pcm = PCM_INPUT3;
            break;
        case AV2_RGsB:
            target_input = TVP_INPUT1;
            target_format = FORMAT_RGsB;
            target_typemask = VIDEO_LDTV|VIDEO_SDTV|VIDEO_EDTV|VIDEO_HDTV;
            target_ths = THS_INPUT_A;
            target_pcm = PCM_INPUT3;
            break;
        case AV3_RGBHV:
            target_input = TVP_INPUT3;
            target_format = FORMAT_RGBHV;
            target_typemask = VIDEO_PC;
            target_ths = THS_STANDBY;
            target_pcm = PCM_INPUT2;
            break;
        case AV3_RGBs:
            target_input = TVP_INPUT3;
            target_format = FORMAT_RGBS;
            target_typemask = VIDEO_LDTV|VIDEO_SDTV|VIDEO_EDTV|VIDEO_HDTV;
            target_ths = THS_STANDBY;
            target_pcm = PCM_INPUT2;
            break;
        case AV3_RGsB:
            target_input = TVP_INPUT3;
            target_format = FORMAT_RGsB;
            target_typemask = VIDEO_LDTV|VIDEO_SDTV|VIDEO_EDTV|VIDEO_HDTV;
            target_ths = THS_STANDBY;
            target_pcm = PCM_INPUT2;
            break;
        case AV3_YPBPR:
            target_input = TVP_INPUT3;
            target_format = FORMAT_YPbPr;
            target_typemask = VIDEO_LDTV|VIDEO_SDTV|VIDEO_EDTV|VIDEO_HDTV;
            target_ths = THS_STANDBY;
            target_pcm = PCM_INPUT2;
            break;
        default:
            break;
        }

        if (target_mode != AV_KEEP) {
            printf("### SWITCH MODE TO %s ###\n", avinput_str[target_mode]);
            cm.avinput = target_mode;
            cm.sync_active = 0;
            ths_source_sel(target_ths, (cm.cc.video_lpf > 1) ? (VIDEO_LPF_MAX-cm.cc.video_lpf) : THS_LPF_BYPASS);
            tvp_disable_output();
#ifdef ENABLE_AUDIO
            DisableAudioOutput();
            if (pcm1862_active)
                pcm_source_sel(target_pcm);
#endif
            tvp_source_sel(target_input, target_format);
            cm.clkcnt = 0; //TODO: proper invalidate
            strncpy(row1, avinput_str[cm.avinput], LCD_ROW_LEN+1);
            strncpy(row2, "    NO SYNC", LCD_ROW_LEN+1);
            if (!menu_active)
                lcd_write_status();
            if (av_init && (tc.def_input == AV_LAST))
                write_userdata(INIT_CONFIG_SLOT);
            av_init = 1;
        }

        // Check here to enable regardless of av_init
        if (tc.tx_mode != cm.cc.tx_mode) {
            HDMITX_SetAVIInfoFrame(HDMI_Unkown, 0, 0, 0, 0);
            TX_enable(tc.tx_mode);
            cm.cc.tx_mode = tc.tx_mode;
            cm.clkcnt = 0; //TODO: proper invalidate
        }
        if ((tc.tx_mode == TX_HDMI) && (tc.hdmi_itc != cm.cc.hdmi_itc)) {
            //EnableAVIInfoFrame(FALSE, NULL);
            printf("setting ITC to %d\n", tc.hdmi_itc);
            HDMITX_SetAVIInfoFrame(HDMI_Unkown, 0, 0, tc.hdmi_itc, cm.hdmitx_pixr_ifr);
            cm.cc.hdmi_itc = tc.hdmi_itc;
        }

        if (av_init) {
            status = get_status(target_input, target_format);

            switch (status) {
            case ACTIVITY_CHANGE:
                if (cm.sync_active) {
                    printf("Sync up\n");
                    sys_ctrl |= VIDGEN_OFF;
                    IOWR_ALTERA_AVALON_PIO_DATA(PIO_0_BASE, sys_ctrl);
                    enable_outputs();
                } else {
                    printf("Sync lost\n");
                    cm.clkcnt = 0; //TODO: proper invalidate
                    tvp_disable_output();
                    //ths_source_sel(THS_STANDBY, 0);
                    strncpy(row1, avinput_str[cm.avinput], LCD_ROW_LEN+1);
                    strncpy(row2, "    NO SYNC", LCD_ROW_LEN+1);
                    if (!menu_active)
                        lcd_write_status();
                }
                break;
            case MODE_CHANGE:
                if (cm.sync_active) {
                    printf("Mode change\n");
                    program_mode();
                }
                break;
            case INFO_CHANGE:
                if (cm.sync_active) {
                    printf("Info change\n");
                    set_videoinfo();
                }
                break;
            default:
                break;
            }
        }

        btn_code_prev = btn_code;
        remote_rpt_prev = remote_rpt;
        target_mode = AV_KEEP;
        usleep(300);    // Avoid executing mainloop multiple times per vsync
    }

    return 0;
}

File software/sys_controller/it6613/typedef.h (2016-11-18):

#ifndef _TYPEDEF_H_
#define _TYPEDEF_H_

//////////////////////////////////////////////////
// data type
//////////////////////////////////////////////////
#ifdef _MCU_
typedef bit BOOL ;
#define _CODE //richard code
#define _IDATA //richard idata
#define _XDATA //richard xdata
#else
typedef int BOOL ;
#define _CODE
#define _IDATA
#define _XDATA
#endif // _MCU_



typedef char CHAR,*PCHAR ;
typedef unsigned char uchar,*puchar ;
typedef unsigned char UCHAR,*PUCHAR ;
typedef unsigned char byte,*pbyte ;
typedef unsigned char BYTE,*PBYTE ;

typedef short SHORT,*PSHORT ;
typedef unsigned short ushort,*pushort ;
typedef unsigned short USHORT,*PUSHORT ;
typedef unsigned short word,*pword ;
typedef unsigned short WORD,*PWORD ;

typedef long LONG,*PLONG ;
typedef unsigned long ulong,*pulong ;
typedef unsigned long ULONG,*PULONG ;
typedef unsigned long dword,*pdword ;
typedef unsigned long DWORD,*PDWORD ;

#define FALSE 0
#define TRUE 1

#define SUCCESS 0
#define FAIL -1

#define ON 1
#define OFF 0

typedef enum _SYS_STATUS {
    ER_SUCCESS = 0,
    ER_FAIL,
    ER_RESERVED
} SYS_STATUS ;

#define abs(x) (((x)>=0)?(x):(-(x)))


typedef enum _Video_State_Type {
    VSTATE_PwrOff = 0,
    VSTATE_SyncWait ,
    VSTATE_SWReset,
    VSTATE_SyncChecking,
    VSTATE_HDCPSet,
    VSTATE_HDCP_Reset,
    VSTATE_ModeDetecting,
    VSTATE_VideoOn,
    VSTATE_Reserved
} Video_State_Type ;


typedef enum _Audio_State_Type {
    ASTATE_AudioOff = 0,
    ASTATE_RequestAudio ,
    ASTATE_ResetAudio,
    ASTATE_WaitForReady,
    ASTATE_AudioOn ,
    ASTATE_Reserved
} Audio_State_Type ;

typedef enum _TXVideo_State_Type {
    TXVSTATE_Unplug = 0,
    TXVSTATE_HPD,
    TXVSTATE_WaitForMode,
    TXVSTATE_WaitForVStable,
    TXVSTATE_VideoInit,
    TXVSTATE_VideoSetup,
    TXVSTATE_VideoOn,
    TXVSTATE_Reserved
} TXVideo_State_Type ;


typedef enum _TXAudio_State_Type {
    TXASTATE_AudioOff = 0,
    TXASTATE_AudioPrepare,
    TXASTATE_AudioOn,
    TXASTATE_AudioFIFOFail,
    TXASTATE_Reserved
} TXAudio_State_Type ;




typedef enum {
    PCLK_LOW = 0 ,
    PCLK_MEDIUM,
    PCLK_HIGH
} VIDEOPCLKLEVEL ;

///////////////////////////////////////////////////////////////////////
// Video Data Type
///////////////////////////////////////////////////////////////////////
#define F_MODE_RGB24  0
#define F_MODE_RGB444  0
#define F_MODE_YUV422 1
#define F_MODE_YUV444 2
#define F_MODE_CLRMOD_MASK 3


#define F_MODE_INTERLACE  1

#define F_MODE_ITU709  (1<<4)
#define F_MODE_ITU601  0

#define F_MODE_0_255   0
#define F_MODE_16_235  (1<<5)

#define F_MODE_EN_UDFILT (1<<6) // output mode only,and loaded from EEPROM
#define F_MODE_EN_DITHER (1<<7) // output mode only,and loaded from EEPROM

#define F_VIDMODE_ITU709    F_MODE_ITU709   // richard add
#define F_VIDMODE_16_235    F_MODE_16_235   // richard add


typedef union _VideoFormatCode 
{
    struct _VFC
    {
        BYTE colorfmt:2 ;
        BYTE interlace:1 ;
        BYTE Colorimetry:1 ;
        BYTE Quantization:1 ;
        BYTE UpDownFilter:1 ;
        BYTE Dither:1 ;
    } VFCCode ;
    unsigned char VFCByte ;
} VideoFormatCode ;

#define T_MODE_CCIR656 (1<<0)
#define T_MODE_SYNCEMB (1<<1)
#define T_MODE_INDDR   (1<<2)
#define T_MODE_PCLKDIV2 (1<<3)
#define T_MODE_DEGEN (1<<4)
#define T_MODE_SYNCGEN (1<<5)
//////////////////////////////////////////////////////////////////
// Audio relate definition and macro.
//////////////////////////////////////////////////////////////////

// for sample clock
#define AUDFS_22p05KHz  4
#define AUDFS_44p1KHz 0
#define AUDFS_88p2KHz 8
#define AUDFS_176p4KHz    12

#define AUDFS_24KHz  6
#define AUDFS_48KHz  2
#define AUDFS_96KHz  10
#define AUDFS_192KHz 14

#define AUDFS_32KHz  3
#define AUDFS_OTHER    1

// Audio Enable
#define ENABLE_SPDIF    (1<<4)
#define ENABLE_I2S_SRC3  (1<<3)
#define ENABLE_I2S_SRC2  (1<<2)
#define ENABLE_I2S_SRC1  (1<<1)
#define ENABLE_I2S_SRC0  (1<<0)

#define AUD_SWL_NOINDICATE  0x0
#define AUD_SWL_16          0x2
#define AUD_SWL_17          0xC
#define AUD_SWL_18          0x4
#define AUD_SWL_20          0xA // for maximum 20 bit
#define AUD_SWL_21          0xD
#define AUD_SWL_22          0x5
#define AUD_SWL_23          0x9
#define AUD_SWL_24          0xB


/////////////////////////////////////////////////////////////////////
// Packet and Info Frame definition and datastructure.
/////////////////////////////////////////////////////////////////////

#define VENDORSPEC_INFOFRAME_TYPE 0x01
#define AVI_INFOFRAME_TYPE  0x02
#define SPD_INFOFRAME_TYPE 0x03
#define AUDIO_INFOFRAME_TYPE 0x04
#define MPEG_INFOFRAME_TYPE 0x05

#define VENDORSPEC_INFOFRAME_VER 0x01
#define AVI_INFOFRAME_VER  0x02
#define SPD_INFOFRAME_VER 0x01
#define AUDIO_INFOFRAME_VER 0x01
#define MPEG_INFOFRAME_VER 0x01

#define VENDORSPEC_INFOFRAME_LEN 8
#define AVI_INFOFRAME_LEN 13
#define SPD_INFOFRAME_LEN 25
#define AUDIO_INFOFRAME_LEN 10
#define MPEG_INFOFRAME_LEN 10

#define ACP_PKT_LEN 9
#define ISRC1_PKT_LEN 16
#define ISRC2_PKT_LEN 16
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

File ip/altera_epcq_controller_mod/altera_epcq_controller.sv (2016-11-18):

// (C) 2001-2015 Altera Corporation. All rights reserved.
// Your use of Altera Corporation's design tools, logic functions and other 
// software and tools, and its AMPP partner logic functions, and any output 
// files any of the foregoing (including device programming or simulation 
// files), and any associated documentation or information are expressly subject 
// to the terms and conditions of the Altera Program License Subscription 
// Agreement, Altera MegaCore Function License Agreement, or other applicable 
// license agreement, including, without limitation, that your use is for the 
// sole purpose of programming logic devices manufactured by Altera and sold by 
// Altera or its authorized distributors.  Please refer to the applicable 
// agreement for further details.


// (C) 2001-2015 Altera Corporation. All rights reserved.
// Your use of Altera Corporation's design tools, logic functions and other 
// software and tools, and its AMPP partner logic functions, and any output 
// files any of the foregoing (including device programming or simulation 
// files), and any associated documentation or information are expressly subject 
// to the terms and conditions of the Altera Program License Subscription 
// Agreement, Altera MegaCore Function License Agreement, or other applicable 
// license agreement, including, without limitation, that your use is for the 
// sole purpose of programming logic devices manufactured by Altera and sold by 
// Altera or its authorized distributors.  Please refer to the applicable 
// agreement for further details.



`timescale 1ps / 1ps

module altera_epcq_controller #(
	parameter CS_WIDTH		= 1,
	parameter ENABLE_4BYTE_ADDR = 1,
	parameter ADDR_WIDTH	= 22,
	parameter ASI_WIDTH		= 1,
	parameter DEVICE_FAMILY = "CYCLONE V",
	parameter ASMI_ADDR_WIDTH = 22,
	parameter CHIP_SELS = 1
)(
	input 	wire		  								clk,
	input 	wire		  								reset_n,
	                                        			
	// ports to access csr                        			
	input 	wire										avl_csr_write,
	input 	wire		  								avl_csr_read,
	input 	wire 	[2:0] 								avl_csr_addr,
	input 	wire 	[31:0] 								avl_csr_wrdata,
	output 	reg 	[31:0] 								avl_csr_rddata,
	output 	reg 		 								avl_csr_rddata_valid,
	output 	reg 			 							avl_csr_waitrequest,
	                                        			
	// ports to access memory        			
	input	wire		  								avl_mem_write,
	input	wire										avl_mem_read,
	input	wire  	[ADDR_WIDTH-1:0]					avl_mem_addr,			
	input	wire	[31:0]								avl_mem_wrdata,
	input	wire 	[3:0]								avl_mem_byteenable,
	input	wire	[6:0]								avl_mem_burstcount,
	output	wire	[31:0]								avl_mem_rddata,
	output	reg											avl_mem_rddata_valid,
	output 	reg 			 							avl_mem_waitrequest,
	
	// interrupt signal
	output	reg 										irq,
	
	// Disable dedicated active serial interface
	input  	wire	[ASI_WIDTH-1:0]						epcq_dataout,
	output  reg											epcq_dclk,
	output  reg		[CS_WIDTH-1:0] 						epcq_scein,
	output  reg		[ASI_WIDTH-1:0]						epcq_sdoin,
	output  reg		[ASI_WIDTH-1:0]						epcq_dataoe,
	
	// ASMI PARALLEL interface
	input   wire	[ASI_WIDTH-1:0]						ddasi_dataoe,
	output  reg 	[ASI_WIDTH-1:0]						ddasi_dataout,
	input   wire 										ddasi_dclk,
	input   wire 	[CS_WIDTH-1:0] 						ddasi_scein,
	input   reg		[ASI_WIDTH-1:0]  					ddasi_sdoin,
	
	input   wire										asmi_busy,
	input   wire										asmi_data_valid,
	input   wire	[7:0]  								asmi_dataout,
	output  reg											asmi_clkin,
	output  reg											asmi_reset,
	output  reg		[CS_WIDTH-1:0] 						asmi_sce,
	output	reg	    [ASMI_ADDR_WIDTH-1:0]  				asmi_addr,
	output  reg		[7:0]  								asmi_datain,
	output  reg											asmi_fast_read,
	output  wire										asmi_rden,
	output  reg											asmi_shift_bytes,
	output  reg 										asmi_en4b_addr,
	output  wire										asmi_wren,
	output  reg											asmi_write,
	
	input   wire										asmi_illegal_erase,
	input   wire										asmi_illegal_write,
	input   wire	[7:0]  								asmi_rdid_out,
	input   wire	[7:0]  								asmi_status_out,
	input   wire	[7:0]  								asmi_epcs_id,
	output  reg											asmi_read_rdid,
	output  reg											asmi_read_status,
	output	reg											asmi_read_sid,
	output  reg 										asmi_bulk_erase,
	output  reg											asmi_sector_erase,
	output  reg											asmi_sector_protect
);
	localparam LOCAL_ADDR_WIDTH = ADDR_WIDTH+2;
	localparam CSR_DATA_WIDTH   = 32;
	localparam LAST_ADDR_BIT    = (ASMI_ADDR_WIDTH == 24) ? 15 :
									(ASMI_ADDR_WIDTH == 32) ? 23 : 15;
	
	reg  [8:0] wr_burstcount_cnt, rd_burstcount_cnt;
	reg	 [8:0] rd_mem_burstcount, wr_mem_burstcount;
	
	wire last_wr_byte;
	wire access_csr_status, access_csr_sid, access_csr_rdid, access_csr_mem_op, access_isr, access_imr, access_sce;
	wire read_status_combi, read_sid_combi, read_rdid_combi, read_isr_combi, read_imr_combi, write_isr_combi, write_imr_combi, write_sce_combi;
	wire bulk_erase_combi, sector_erase_combi, sector_protect_combi;
	wire wren_combi, illegal_write_combi, illegal_erase_combi;
	wire m_illegal_write_combi, m_illegal_erase_combi;
	wire read_mem_combi, write_mem_combi;
	wire data_valid_combi, pending_wr_data;
	wire detect_addroffset;
	wire [8:0] wfifo_data_in_0, wfifo_data_in_1, wfifo_data_in_2, wfifo_data_in_3;
	wire [ADDR_WIDTH-1:0] temp_mem_addr;
	
	reg reset_n_reg;
	reg wr_mem_waitrequest, local_waitrequest;
	reg illegal_write_reg, illegal_erase_reg, m_illegal_write_reg, m_illegal_erase_reg;
	reg read_status_valid, read_sid_valid, read_rdid_valid, read_isr_valid, read_imr_valid;
	reg read_status_en, read_sid_en, read_rdid_en;
	reg wren_internal;
	reg [LOCAL_ADDR_WIDTH-1:0] wr_mem_addr;
	reg [7:0] rd_data_reg [4];
	reg [3:0][8:0] wr_data_reg;
	reg [1:0] rd_cnt;
	reg [1:0] wr_cnt;
	reg [3:0] wr_data_reg_full;
	reg detect_addroffset_reg, asmi_busy_reg;
	reg [2:0] temp_sce;
	
	// Direct connection
	assign asmi_clkin 		= clk;
	assign asmi_reset 		= ~reset_n;
	assign ddasi_dataout 	= epcq_dataout;
	assign epcq_dclk 		= ddasi_dclk;
	assign epcq_scein		= ddasi_scein;
	assign epcq_sdoin		= ddasi_sdoin;
	assign epcq_dataoe		= ddasi_dataoe;
	
	// chip select
	generate if (DEVICE_FAMILY == "Arria 10") begin
		always @(posedge clk or negedge reset_n) begin
			if (~reset_n) begin
				asmi_sce			<= {CS_WIDTH{1'b0}};
			end 
// to pack the address space this is needed
			else if (write_mem_combi || read_mem_combi) begin
				if (CHIP_SELS == 1 ) 					
					asmi_sce			<= 3'b001;
				else if (CHIP_SELS == 2 && avl_mem_addr[ADDR_WIDTH-1] == 0) 
					asmi_sce			<= 3'b001;
				else if (CHIP_SELS == 2 && avl_mem_addr[ADDR_WIDTH-1] == 1) 
					asmi_sce			<= 3'b010;
				else if (CHIP_SELS == 3 && avl_mem_addr[ADDR_WIDTH-1] == 1)	
					asmi_sce			<= 3'b100;
				else if (CHIP_SELS == 3 && avl_mem_addr[ADDR_WIDTH-1:ADDR_WIDTH-2] == 0) 	
					asmi_sce			<= 3'b001;
				else if (CHIP_SELS == 3 && avl_mem_addr[ADDR_WIDTH-1:ADDR_WIDTH-2] == 1)
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

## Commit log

2016-04-26 initial commit diy-audio v0.69
    [OSSC_HDMI_Audio.brd, OSSC_HDMI_Audio.sch]
2016-07-08 DIY audio PCB for OSSC v1.5 Side note: The outline of this board (dimension layer) is not tested so far. I don’t have a DIY-v1.5 of the OSSC; just pics. So please give feedback to me for fitting if y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
    [OSSC_HDMI_Audio_v1.3.brd, OSSC_HDMI_Audio_v1.3.sch, OSSC_HDMI_Audio_v1.5.brd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]
2016-08-08 rename PCB files (add ‚A3‘ as on silkscreen)
    [OSSC_HDMI_Audio_v1.3_A3.brd, OSSC_HDMI_Audio_v1.3_A3.sch, OSSC_HDMI_Audio_v1.5_A3.brd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]
2016-08-08 Audio Add-On (Version ‚A3b’) with pads for GND and audio (in) allowing installation with wires to the SCART jack. Thanks to Kel for this modification.
    [OSSC_HDMI_Audio_v1.5_A3b.brd, OSSC_HDMI_Audio_v1.5_A3b.sch]
2016-09-12 allow info frames for OSSCs with DVI output in HDMI mode
2016-09-25 External MCLK option to increase compatibility - thanks to Ken (once again ;) ) for testing (and being patient during the tests). There were a lot of others tests before we end up with this solution.
2016-09-25 PCB files with a pad for mclk to IT6613E
    [OSSC_HDMI_Audio_v1.3_A4.brd, OSSC_HDMI_Audio_v1.3_A4.sch, OSSC_HDMI_Audio_v1.5_A4a.brd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]
2017-05-30 Bugfix: audio down-sampling setting
    [it6613_drv.c]
2017-05-30 Setting MCLK adjust command and small bugfix
    [it6613_drv.c, it6613_drv.h]
2017-06-04 Bugfix: screwed up register definitions
    [it6613_drv.c, it6613_drv.h]
2017-11-10 initial commit for automatic LCD backlight control: - hardware driven, software code remains unchanged - BL turned on with any button press (either PCB or RF) - button codes are forwarded to software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
2017-11-10 reduce BL on time down to 3.5s on power cycle

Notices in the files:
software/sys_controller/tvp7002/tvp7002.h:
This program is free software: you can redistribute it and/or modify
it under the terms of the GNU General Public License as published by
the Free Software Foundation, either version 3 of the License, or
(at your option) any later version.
